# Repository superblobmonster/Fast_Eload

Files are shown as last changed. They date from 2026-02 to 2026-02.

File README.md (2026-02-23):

# Fast_Eload
Designed in KiCad 9.0.7 and FreeCAD 1.0.2

License: CC-BY-SA-4.0



## Design Specs
+ 10A/us slew rate
+ 15A RMS, 50A peak, 20A fuse
+ 100W (To be verified) average, peak power limited by FET SOA.
+ 100V input, 150V TVS protection, 250V+ rated parts.
+ 10V external power supply

## Design notes
+ Produce with 2oz copper
+ Fill and cap vias, or plate solid
+ Thinner PCB the better for thermal performance
+ Turn-off slew rates > 15A/us causes instability, root cause unknown

## Parts
+ CCA BOM: https://www.digikey.com/en/mylists/list/430F3M7L10

Additional parts/accessories:
+ Copper shim-stock: https://www.mcmaster.com/products/metals/copper-2~/shape~sheet/thickness~0-032/thickness~0-040/thickness~0-04/
+ TIM
+ Ring terminals
+ M3x4 screws
+ Amphenol MMCX to BNC: 095-850-207-006
+ Tektronix probe tip adaptor to BNC: 13036700
+ Ribbon cable assembly: 71600-308LF

## TODO and Notes
+ Validate thermal performance
+ Measure control bandwidth
+ Create control board with:
  + 10MS/s DAC
  + Slew rate limiting
  + V/I Monitoring: ADS7253?
    + Unregulation detection
    + SOA protections
  + Isolated input signal, 10MS/s ADC
  + Paralleling features, enable controls
+ Add temperature monitoring
+ Heatsink and interface design for equipment rack enclosure
+ Design a fully electrically isolated THT version with a SOT-227 FET

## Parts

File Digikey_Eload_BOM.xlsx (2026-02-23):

Country of Origin may be different at time of shipment.
The HTSUS and ECCN information shown is for informational purposes only and is not a representation or warranty as to the accuracy or reliability of these classifications. All information is provided "as is" and is subject to change without notice. Any use made of the information provided is without recourse to Digi-Key and at the user's risk.
Index | Manufacturer Part Number | Manufacturer Name | Qty Per Assembly | Description | Availability | Stock Status | Requested Part Number | Lead Weeks | Datasheet | Reference Designator | US Import Tariff | Note | Part Status | RoHS Status | REACH Status | Moisture Sensitivity Level (MSL) | ECCN | HTSUS | Country of Origin | Environmental Information | Original Part numbers | Unit of Measure | Image
1 | T491A106M016AT | KEMET | 1 | CAP TANT 10UF 20% 16V 1206 | 127,321 | In Stock | T491A106M016AT | 16 | https://yageogroup.com/content/datasheet/asset/file/KEM_T2005_T491 | C1 | N/A |  | Active | ROHS3 Compliant | REACH Unaffected | 1 (Unlimited) | EAR99 | 8532.21.0050 | Mexico |  | T491A106M016AT | EACH | https://mm.digikey.com/Volume0/opasdata/d220001/medias/images/2578/T491%20SERIES%203.2L%2C1.6W.jpg
2 | C0603C105K4RACTU | KEMET | 2 | CAP CER 1UF 16V X7R 0603 | 1,577,470 | In Stock | C0603C105K4RACTU | 12 | https://yageogroup.com/content/datasheet/asset/file/KEM_C1002_X7R_SMD | C2,C3 | N/A |  | Active | ROHS3 Compliant | REACH Unaffected | 1 (Unlimited) | EAR99 | 8532.24.0020 | Taiwan |  | C0603C105K4RACTU | EACH | https://mm.digikey.com/Volume0/opasdata/d220001/medias/images/4322/cut-tape-render.jpg
3 | C0603C202J5GACTU | KEMET | 1 | CAP CER 2000PF 50V C0G/NP0 0603 | 18,924 | In Stock | C0603C202J5GACTU | 13 | https://yageogroup.com/content/datasheet/asset/file/KEM_C1003_C0G_SMD | C4 | N/A |  | Active | ROHS3 Compliant | REACH Unaffected | 1 (Unlimited) | EAR99 | 8532.24.0020 | Mexico |  | C0603C202J5GACTU | EACH | https://mm.digikey.com/Volume0/opasdata/d220001/medias/images/5352/0603-%281608-Metric%29-Ceramic-Capacitor.jpg
4 | C0603C681F5GACTU | KEMET | 1 | CAP CER 680PF 50V C0G/NP0 0603 | 57,597 | In Stock | C0603C681F5GACTU | 11 | https://yageogroup.com/content/datasheet/asset/file/KEM_C1003_C0G_SMD | C6 | N/A |  | Active | ROHS3 Compliant | REACH Unaffected | 1 (Unlimited) | EAR99 | 8532.24.0020 | Mexico |  | C0603C681F5GACTU | EACH | https://mm.digikey.com/Volume0/opasdata/d220001/medias/images/5352/0603-%281608-Metric%29-Ceramic-Capacitor.jpg
5 | C0603C100J5GACTU | KEMET | 2 | CAP CER 10PF 50V C0G/NP0 0603 | 335,018 | In Stock | 399-C0603C100J5GACTUTR-ND | 13 | https://yageogroup.com/content/datasheet/asset/file/KEM_C1003_C0G_SMD | C7, C9 | N/A |  | Active | ROHS3 Compliant | REACH Unaffected | 1 (Unlimited) | EAR99 | 8532.24.0020 | Taiwan |  | 399-C0603C100J5GACTUTR-ND | EACH | https://mm.digikey.com/Volume0/opasdata/d220001/medias/images/4322/cut-tape-render.jpg
6 | C1206X103JAGACAUTO | KEMET | 1 | CAP CER 10000PF 250V NP0 1206 | 20,191 | In Stock | C1206X103JAGACAUTO | 20 | https://search.kemet.com/download/specsheet/C1206X103JAGACAUTO | C8 | N/A |  | Active | ROHS3 Compliant | REACH Unaffected | 1 (Unlimited) | EAR99 | 8532.24.0020 | Mexico |  | C1206X103JAGACAUTO | EACH | https://mm.digikey.com/Volume0/opasdata/d220001/medias/images/208/1206-%283216-Metric%29-3%2C20x1%2C60x1%2C00mm.jpg
7 | SM6T150A | STMicroelectronics | 1 | TVS DIODE 128VWM 207VC SMB | 7,339 | In Stock | SM6T150A | 13 | https://www.st.com/resource/en/datasheet/cd00000725.pdf | D1 | May apply on shipments to the U.S. |  | Active | ROHS3 Compliant | REACH Unaffected | 1 (Unlimited) | EAR99 | 8541.10.0080 | China |  | SM6T150A | EACH | https://mm.digikey.com/Volume0/opasdata/d220001/medias/images/6256/497%7ESMB%28DO214AA%29%7E%7E2.jpg
8 | DDZ5V6BSF-7 | Diodes Incorporated | 1 | DIODE ZENER 5.6V 500MW SOD323F | 9,376 | In Stock | DDZ5V6BSF-7DITR-ND | 24 | https://www.diodes.com/assets/Datasheets/ds31987.pdf | D2, D3 | May apply on shipments to the U.S. |  | Active | ROHS3 Compliant | REACH Unaffected | 1 (Unlimited) | EAR99 | 8541.10.0050 | China | https://mm.digikey.com/Volume0/opasdata/d220001/medias/docus/6731/Diode%20RoHS3%20REACH%20247%20Jan%202025%20Statement.pdf | DDZ5V6BSF-7DITR-ND | EACH | https://mm.digikey.com/Volume0/opasdata/d220001/medias/images/6210/31%7ESOD323F%7E%7E2.jpg
9 | 0683G9200-01 | Bel Fuse Inc. | 1 | FUSE CERM 20A 350VAC 125VDC 2SMD | 724 | In Stock | 0683G9200-01 | 8 | https://belfuse.com/media/datasheets/products/circuit-protection/ds-CP-0683G-series.pdf | F1 | May apply on shipments to the U.S. |  | Active | ROHS3 Compliant | REACH Unaffected | 1 (Unlimited) | EAR99 | 8536.10.0040 | China |  | 0683G9200-01 | EACH | https://mm.digikey.com/Volume0/opasdata/d220001/medias/images/4693/MFG_img-bcp-0683G_v1.jpg
10 | TSM-104-01-L-DV-P-TR | Samtec Inc. | 1 | CONN HEADER SMD 8POS 2.54MM | 9,183 | In Stock | SAM13286TR-ND | 4 | https://suddendocs.samtec.com/catalog_english/tsm.pdf | J1 | N/A |  | Active | ROHS3 Compliant | REACH Unaffected | 1 (Unlimited) | EAR99 | 8536.69.4040 | United States |  | SAM13286TR-ND | EACH | https://mm.digikey.com/Volume0/opasdata/d220001/medias/images/1118/TSM-8pos-01-gold-tin-DV.jpg
11 | 66012102111404 | Würth Elektronik | 4 | MMCX SMT PCB JACK, STRAIGHT, 5.0 | 16,256 | In Stock | 732-14187-2-ND | 16 | https://www.we-online.com/components/products/datasheet/66012102111404.pdf | J2, J4, J6, J7 | N/A | OPTIONAL | Active | ROHS3 Compliant | REACH Affected | Not Applicable | EAR99 | 8536.69.4010 | Taiwan | https://mm.digikey.com/Volume0/opasdata/d220001/medias/docus/744/Certificate_of_Compliance_ROHS.pdf | 732-14187-2-ND | EACH | https://mm.digikey.com/Volume0/opasdata/d220001/medias/images/695/MFG_66012102111404.jpg
12 | 7466203 | Würth Elektronik | 2 | TERM REDCUBE M3 1PIN SMD | 3,479 | In Stock | 7466203 | 18 | https://www.we-online.com/components/products/datasheet/7466203.pdf | J3,J5 | N/A |  | Active | ROHS3 Compliant | REACH Affected | 1 (Unlimited) | EAR99 | 8536.90.4000 | Germany | https://mm.digikey.com/Volume0/opasdata/d220001/medias/docus/744/Certificate_of_Compliance_ROHS.pdf | 7466203 | EACH | https://mm.digikey.com/Volume0/opasdata/d220001/medias/images/409/7466203.JPG
13 | 7449152022 | Würth Elektronik | 1 | FIXED IND 22NH 40A 0.55 MOHM SMD | 408 | In Stock | 7449152022 | 12 | https://www.we-online.com/components/products/datasheet/7449152022.pdf | L1 | May apply on shipments to the U.S. |  | Active | ROHS3 Compliant | REACH Unaffected | 1 (Unlimited) | EAR99 | 8504.50.8000 | China | https://mm.digikey.com/Volume0/opasdata/d220001/medias/docus/744/Certificate_of_Compliance_ROHS.pdf | 7449152022 | EACH | https://mm.digikey.com/Volume0/opasdata/d220001/medias/images/39/MFG_WE-ACHC-Series.jpg
14 | SGT070R70HTO | STMicroelectronics | 1 | 700 V, 53 MOHM TYP., 26 A, E-MOD | 426 | In Stock | 497-SGT070R70HTOTR-ND | 99 | https://www.st.com/resource/en/datasheet/sgt070r70hto.pdf | Q2 | N/A |  | Active | ROHS3 Compliant | REACH Unaffected | 3 (168 Hours) | EAR99 | 8541.29.0055 | China |  | 497-SGT070R70HTOTR-ND | EACH | https://mm.digikey.com/Volume0/opasdata/d220001/medias/images/6256/497%7EDM00276569%7E%7E8-View-2.jpg
15 | PWR263S-35-R100F | Bourns Inc. | 1 | RES 0.1 OHM 1% 35W D2PAK | 1,649 | In Stock | 118-PWR263S-35-R100F-ND | 8 | https://www.bourns.com/docs/Product-Datasheets/PWR263S-35.pdf | R1 | N/A |  | Active | ROHS3 Compliant | REACH Unaffected | 1 (Unlimited) | EAR99 | 8533.29.0000 | Costa Rica | https://www.bourns.com/docs/rohs-cofc/pwr2_coc.pdf?sfvrsn=edf9608a_6|https://www.bourns.com/docs/Product-MDS/PWR263S-35_MDS.pdf | 118-PWR263S-35-R100F-ND | EACH | https://mm.digikey.com/Volume0/opasdata/d220001/medias/images/6163/118%7ETO263-D2PAK%7E%7E2.jpg
16 | IGT65R025D2ATMA1 | Infineon Technologies | 0 | GANFET N-CH 650V 70A 8PSFN | 0 | Normally Stocking | IGT65R025D2ATMA1 | 18 | https://www.infineon.com/dgdl/Infineon-IGT65R025D2-DataSheet-v01_00-EN.pdf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 | Q2 | N/A | ALTERNATE | Active | ROHS3 Compliant | REACH Unaffected | 1 (Unlimited) | EAR99 | 8541.29.0055 | Germany |  | IGT65R025D2ATMA1 | EACH | https://mm.digikey.com/Volume0/opasdata/d220001/derivates/6/003/227/345/MFG_448%7EP-PG-HSOF-8-12%7E%7E8_web%28640x640%29.jpg
17 | D2TO035CR1000FTE3 | Vishay Sfernice | 0 | RES 0.1 OHM 1% 35W TO263 | 100 | In Stock | D2TO035CR1000FTE3 | 8 | https://www.vishay.com/docs/51058/d2to35.pdf | R1 | N/A | ALTERNATE | Active | ROHS3 Compliant | REACH Affected | 1 (Unlimited) | EAR99 | 8533.29.0000 | Czech Republic |  | D2TO035CR1000FTE3 | EACH | https://mm.digikey.com/Volume0/opasdata/d220001/derivates/6/003/240/902/MFG_716%7ETO263%28D2PAK%29%7E%7E2_web%28640x640%29.jpg
18 | CRCW060310K0FKEA | Vishay Dale | 6 | RES SMD 10K OHM 1% 1/8W 0603 | 4,084,407 | In Stock | CRCW060310K0FKEA | 12 | https://www.vishay.com/docs/20035/dcrcwe3.pdf | R2,R7,R10,R11,R19,R20 | N/A |  | Active | ROHS3 Compliant | REACH Unaffected | 1 (Unlimited) | EAR99 | 8533.21.0030 | Taiwan |  | CRCW060310K0FKEA | EACH | https://mm.digikey.com/Volume0/opasdata/d220001/medias/images/4322/cut-tape-render.jpg
19 | CRCW060349R9FKEA | Vishay Dale | 2 | RES SMD 49.9 OHM 1% 1/8W 0603 | 293,361 | In Stock | CRCW060349R9FKEA | 12 | https://www.vishay.com/docs/20035/dcrcwe3.pdf | R3,R4 | N/A |  | Active | ROHS3 Compliant | REACH Unaffected | 1 (Unlimited) | EAR99 | 8533.21.0030 | Taiwan |  | CRCW060349R9FKEA | EACH | https://mm.digikey.com/Volume0/opasdata/d220001/medias/images/4322/cut-tape-render.jpg
20 | CRCW060320R0FKEA | Vishay Dale | 2 | RES SMD 20 OHM 1% 1/8W 0603 | 122,766 | In Stock | CRCW060320R0FKEA | 12 | https://www.vishay.com/docs/20035/dcrcwe3.pdf | R5,R18 | N/A |  | Active | ROHS3 Compliant | REACH Unaffected | 1 (Unlimited) | EAR99 | 8533.21.0030 | Taiwan |  | CRCW060320R0FKEA | EACH | https://mm.digikey.com/Volume0/opasdata/d220001/medias/images/2491/CRCW%200603%20%281608metric%29.jpg
21 | CRCW06031M00FKEA | Vishay Dale | 2 | RES SMD 1M OHM 1% 1/8W 0603 | 264,389 | In Stock | 541-1.00MHCT-ND | 12 | https://www.vishay.com/docs/20035/dcrcwe3.pdf | R6, R21 | N/A |  | Active | ROHS3 Compliant | REACH Unaffected | 1 (Unlimited) | EAR99 | 8533.21.0030 | Israel |  | 541-1.00MHCT-ND | EACH | https://mm.digikey.com/Volume0/opasdata/d220001/medias/images/4322/cut-tape-render.jpg
22 | CRCW060310R0FKEA | Vishay Dale | 2 | RES SMD 10 OHM 1% 1/8W 0603 | 136,613 | In Stock | CRCW060310R0FKEA | 12 | https://www.vishay.com/docs/20035/dcrcwe3.pdf | R8,R16 | N/A |  | Active | ROHS3 Compliant | REACH Unaffected | 1 (Unlimited) | EAR99 | 8533.21.0030 | Taiwan |  | CRCW060310R0FKEA | EACH | https://mm.digikey.com/Volume0/opasdata/d220001/medias/images/4322/cut-tape-render.jpg
23 | CRCW06031K00FKEA | Vishay Dale | 4 | RES SMD 1K OHM 1% 1/8W 0603 | 754,225 | In Stock | CRCW06031K00FKEA | 12 | https://www.vishay.com/docs/20035/dcrcwe3.pdf | R12,R13,R14,R15 | N/A |  | Active | ROHS3 Compliant | REACH Unaffected | 1 (Unlimited) | EAR99 | 8533.21.0030 | Taiwan |  | CRCW06031K00FKEA | EACH | https://mm.digikey.com/Volume0/opasdata/d220001/medias/images/4322/cut-tape-render.jpg
24 | RCWE0805R100FKEA | Vishay Dale | 1 | RES 0.1 OHM 1% 1/4W 0805 | 88,338 | In Stock | RCWE0805R100FKEA | 15 | https://www.vishay.com/docs/20019/rcwe.pdf | R17 | N/A |  | Active | ROHS3 Compliant | REACH Unaffected | 1 (Unlimited) | EAR99 | 8533.21.0030 | Israel |  | RCWE0805R100FKEA | EACH | https://mm.digikey.com/Volume0/opasdata/d220001/medias/images/2584/TFPT%201206%20%283216metric%29.jpg
25 | 3214W-1-201E | Bourns Inc. | 2 | TRIMMER 200 OHM 0.25W J LEAD TOP | 17,775 | In Stock | 3214W-1-201E | 7 | https://www.bourns.com/docs/Product-Datasheets/3214.pdf | RV1,RV2 | N/A |  | Active | ROHS3 Compliant | REACH Affected | 1 (Unlimited) | EAR99 | 8533.40.8050 | Costa Rica | https://mm.digikey.com/Volume0/opasdata/d220001/medias/docus/6657/Bourns%20REACH%20247%20Jan%202025%20Statement.pdf|https://www.bourns.com/docs/rohs-cofc/cofc_trim4.pdf?sfvrsn=41f62244_2 | 3214W-1-201E | EACH | https://mm.digikey.com/Volume0/opasdata/d220001/medias/images/2375/3214W%20SERIES.jpg
26 | THJP0612AST1 | Vishay Dale Thin Film | 23 | THERMAL JUMPER 0612 30 MIL LEAD- | 29,155 | In Stock | THJP0612AST1 | 13 | https://www.vishay.com/docs/60157/thjp.pdf | TJ1,TJ2,TJ3,TJ4,TJ5,TJ6,TJ7,TJ8 | N/A |  | Active | ROHS3 Compliant | REACH Unaffected | 1 (Unlimited) | EAR99 | 8533.21.0030 | United States |  | THJP0612AST1 | EACH | https://mm.digikey.com/Volume0/opasdata/d220001/medias/images/210/MFG_THJP1225.jpg
27 | 5015 | Keystone Electronics | 5 | PC TEST POINT MINIATURE | 736,814 | In Stock | 36-5015TR-ND | 11 | https://www.keyelco.com/userAssets/file/M65p55.pdf | TP1,TP2,TP4,TP5,TP6,TP7,TP8,TP9,TP10 | May apply on shipments to the U.S. |  | Active | ROHS3 Compliant | REACH Unaffected | 1 (Unlimited) | EAR99 | 8536.90.4000 | China | https://www.keyelco.com/userAssets/file/RoHS_Statement.pdf|https://www.keyelco.com/userAssets/file/reach.pdf|https://www.keyelco.com/userAssets/file/Keystone-Prop65%20Declare2022.pdf | 36-5015TR-ND | EACH | https://mm.digikey.com/Volume0/opasdata/d220001/medias/images/827/5015.jpg
28 | ADA4807-4ARUZ-R7 | Analog Devices Inc. | 1 | IC OPAMP VFB 4 CIRCUIT 14TSSOP | 3,641 | In Stock | ADA4807-4ARUZ-R7 | 19 | https://www.analog.com/media/en/technical-documentation/data-sheets/ADA4807-1_4807-2_4807-4.pdf | U1 | N/A |  | Active | ROHS3 Compliant | REACH Unaffected | 1 (Unlimited) | EAR99 | 8542.33.0001 | Philippines |  | ADA4807-4ARUZ-R7 | EACH | https://mm.digikey.com/Volume0/opasdata/d220001/medias/images/4896/505%7ERU-14%7ERU%7E14.JPG

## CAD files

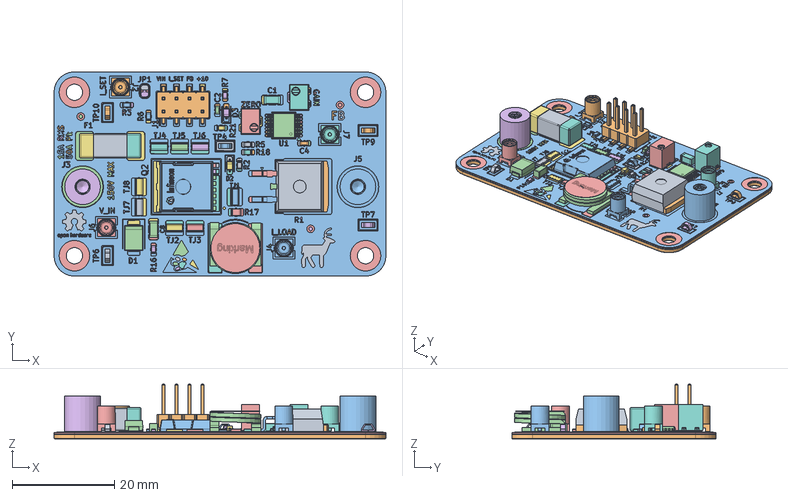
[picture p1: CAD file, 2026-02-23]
Heat_Spreader_Assy.FCStd
65.0 x 40.0 x 10.8 mm
FET_PLATE
GND_PLATE
R_0612_1632Metric
C_0603_1608Metric
MMCX_Wuerth_66012102111404
Wurth_Terminal_7466203_rev1
Ceramic_Fuse_0684L9400-01
Ceramic_Fuse_0684L9400-002
Ceramic_Fuse_0684L9400-003
R_0603_1608Metric
C_1206_3216Metric
Bourns_Pot_3214W
D_SOD-323
R_0612_1632Metric001
R_0603_1608Metric001
Modular_Load 1.13.1
Modular_Load 1.13.002
Modular_Load 1.13.003
Modular_Load 1.13.004
Modular_Load 1.13.005
R_0603_1608Metric002
R_0603_1608Metric003
R_0612_1632Metric002
R_0603_1608Metric004
MMCX_Wuerth_66012102111405
Wurth_Terminal_7466203_rev002
TSSOP-14_4.4x5mm_P0.65mm
R_0612_1632Metric003
R_0603_1608Metric005
PG-HSOF-8_3D
PG-HSOF-8_3D001
PG-HSOF-8_3D002
PG-HSOF-8_3D003
PG-HSOF-8_3D004
PG-HSOF-8_3D005
PG-HSOF-8_3D006
PG-HSOF-8_3D007
PG-HSOF-8_3D008
PG-HSOF-8_3D009
PG-HSOF-8_3D010
PG-HSOF-8_3D011
PG-HSOF-8_3D012
PG-HSOF-8_3D013
PG-HSOF-8_3D014
PG-HSOF-8_3D015
PG-HSOF-8_3D016
MMCX_Wuerth_66012102111406
PinHeader_2x04_P2.54mm_Vertical_SMD
MMCX_Wuerth_66012102111407
Core
Foil
R_0612_1632Metric004
D_SOD-324
C_1206_3216Metric001
R_0603_1608Metric006
D_SMB
R_0805_2012Metric
R_0612_1632Metric005
Bourns_Pot_3214W001
R_0612_1632Metric006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

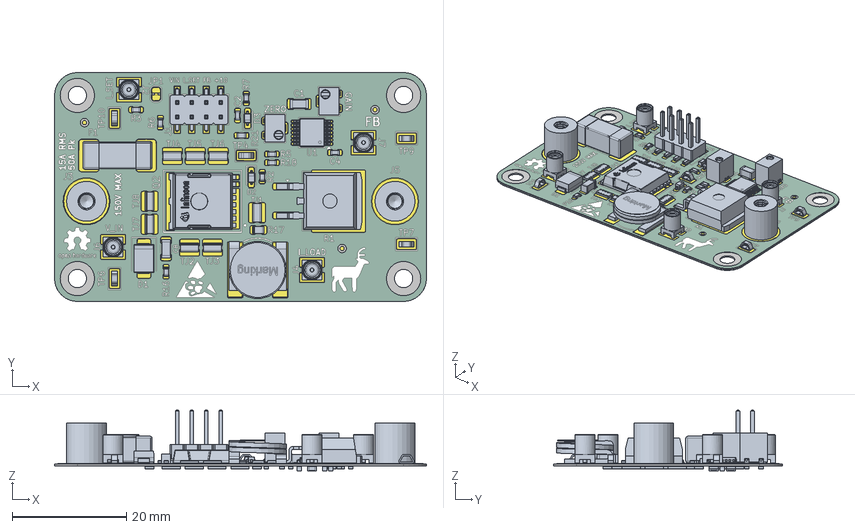
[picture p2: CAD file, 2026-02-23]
3D_Models/Modular_Load.step
65.0 x 40.0 x 10.6 mm
R_0612_1632Metric x 23
C_0603_1608Metric x 6
MMCX_Wuerth_66012102111404 x 4
Wurth_Terminal_7466203_rev1 x 2
Ceramic_Fuse_0684L9400-01
R_0603_1608Metric x 18
C_1206_3216Metric x 2
Bourns_Pot_3214W x 2
D_SOD-323 x 2
Modular_Load 1.13.1
TSSOP-14_4.4x5mm_P0.65mm
PG-HSOF-8_3D
PinHeader_2x04_P2.54mm_Vertical_SMD
Core
Foil
D_SMB
R_0805_2012Metric
Modular_Load_copper
Modular_Load_silkscreen x 2
Modular_Load_soldermask x 2
Modular_Load_PCB

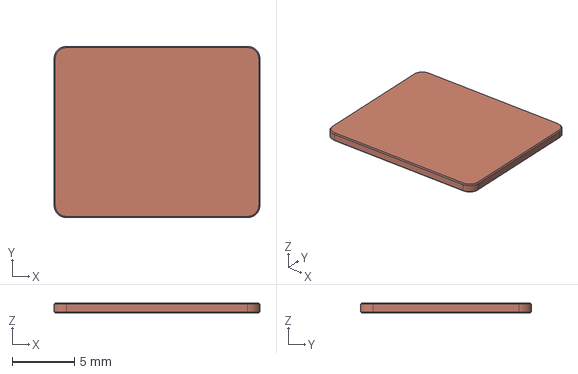
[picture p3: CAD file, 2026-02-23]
3D_Models/FET_PLATE.step
16.6 x 13.8 x 0.81 mm

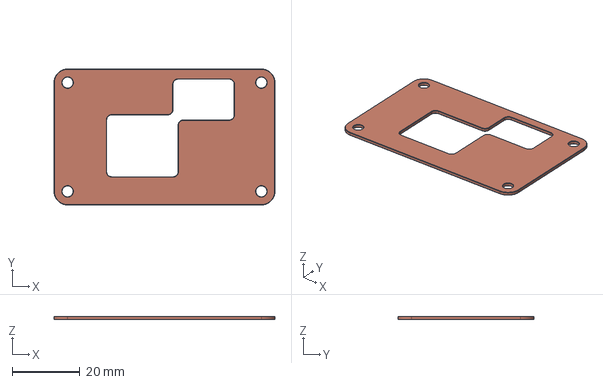
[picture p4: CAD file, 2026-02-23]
3D_Models/GND_PLATE.step
65.0 x 40.0 x 1.00 mm

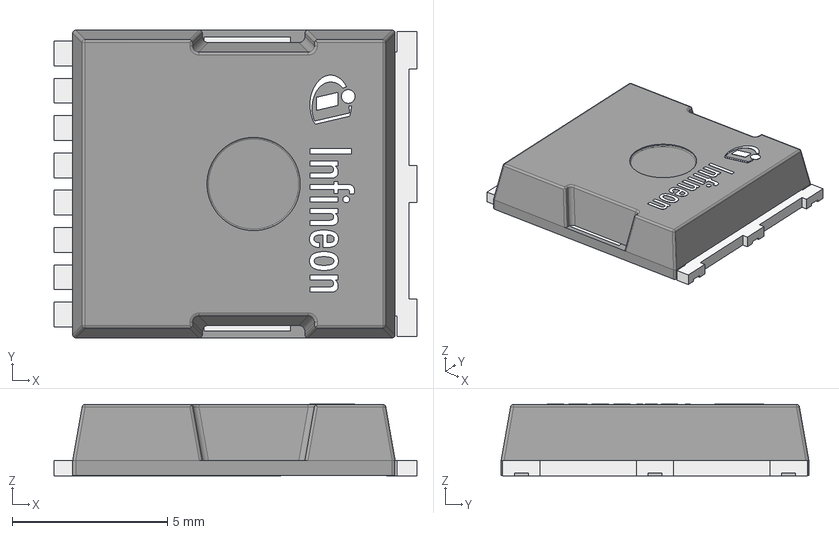
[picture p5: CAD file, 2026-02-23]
3D_Models/PG-HSOF-8_3D.stp
11.7 x 9.90 x 2.31 mm

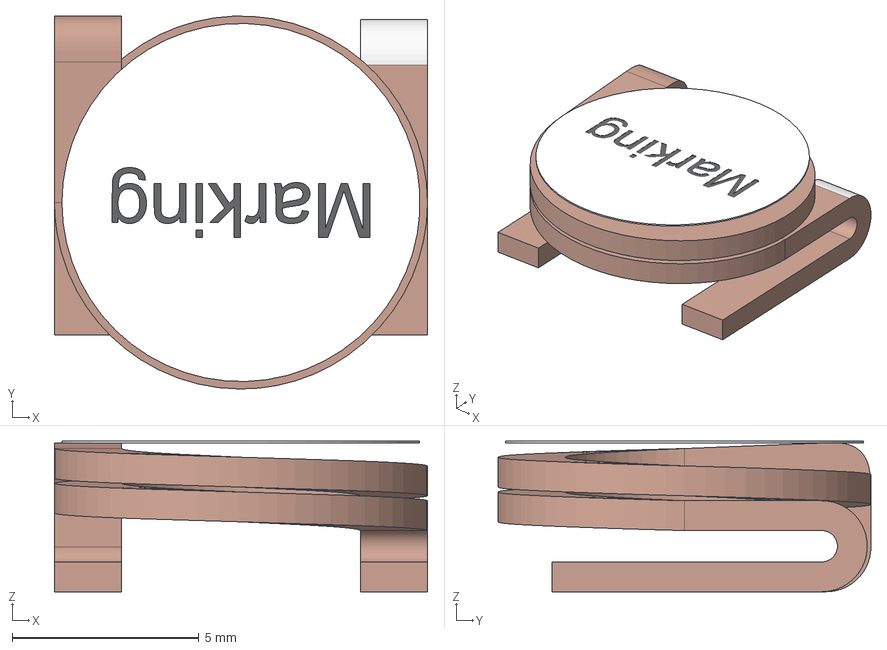
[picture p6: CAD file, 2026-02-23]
3D_Models/Inductor_WE-ACHC-7449150023Rev1.stp
10.0 x 10.00 x 4.04 mm
Core
Foil

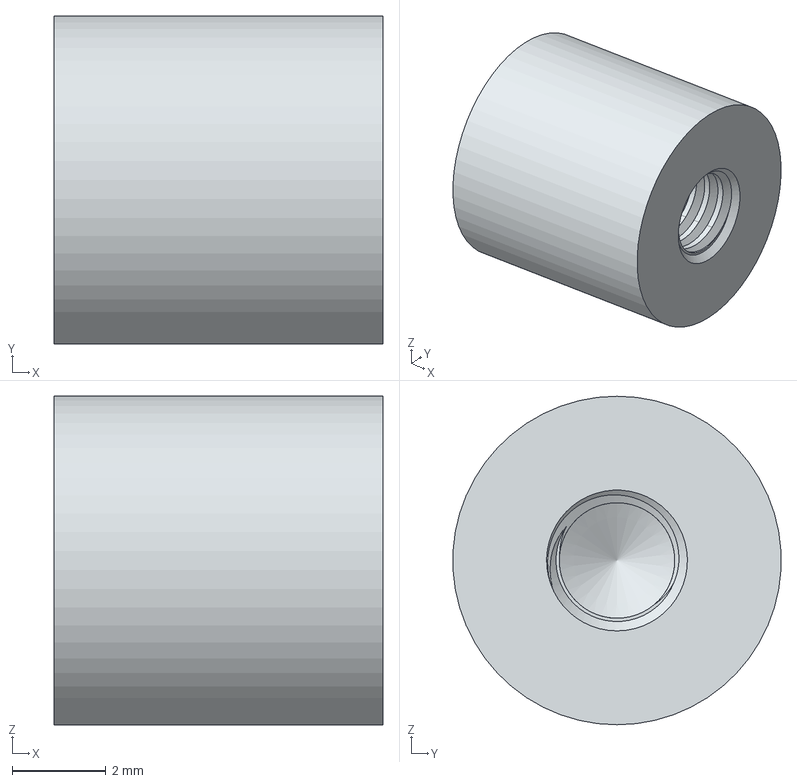
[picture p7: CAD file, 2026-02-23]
3D_Models/Wurth_Terminal_7466203_rev1.stp
7.00 x 6.99 x 7.00 mm

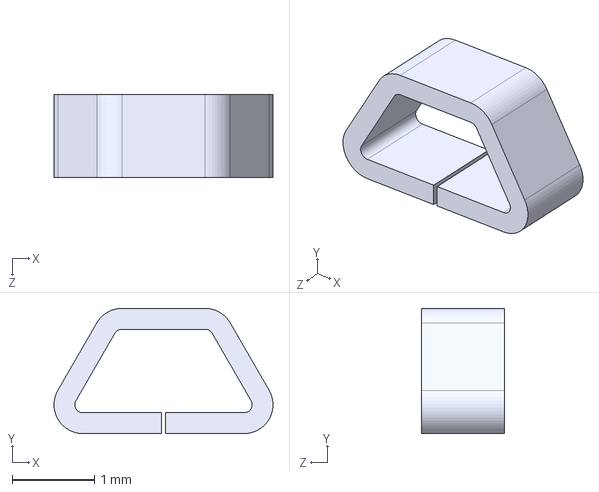
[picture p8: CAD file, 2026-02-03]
3D_Models/5015.step
2.67 x 1.52 x 1.02 mm

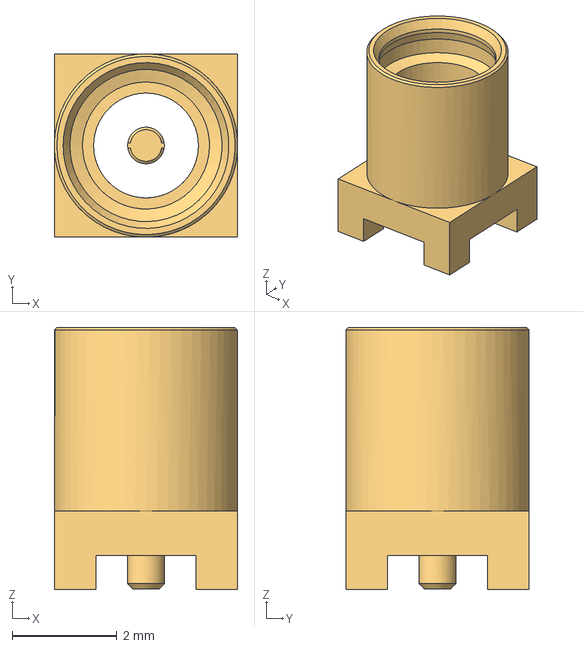
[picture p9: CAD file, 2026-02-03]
3D_Models/MMCX_Wuerth_66012102111404.stp
3.50 x 3.50 x 5.00 mm

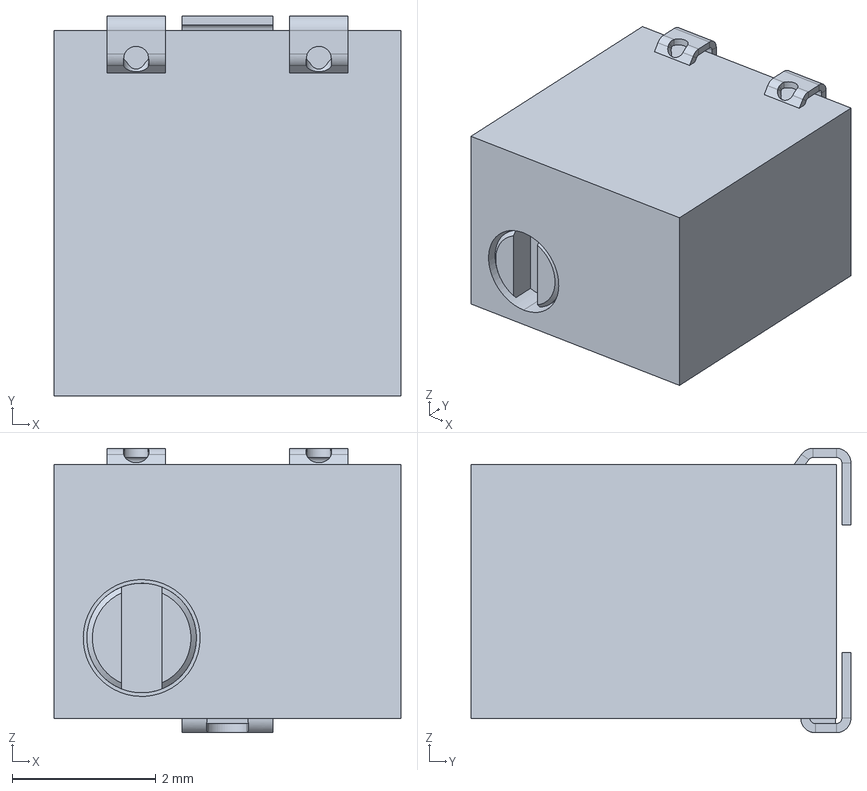
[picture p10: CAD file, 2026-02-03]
3D_Models/Bourns_Pot_3214W.stp
4.83 x 5.28 x 3.96 mm

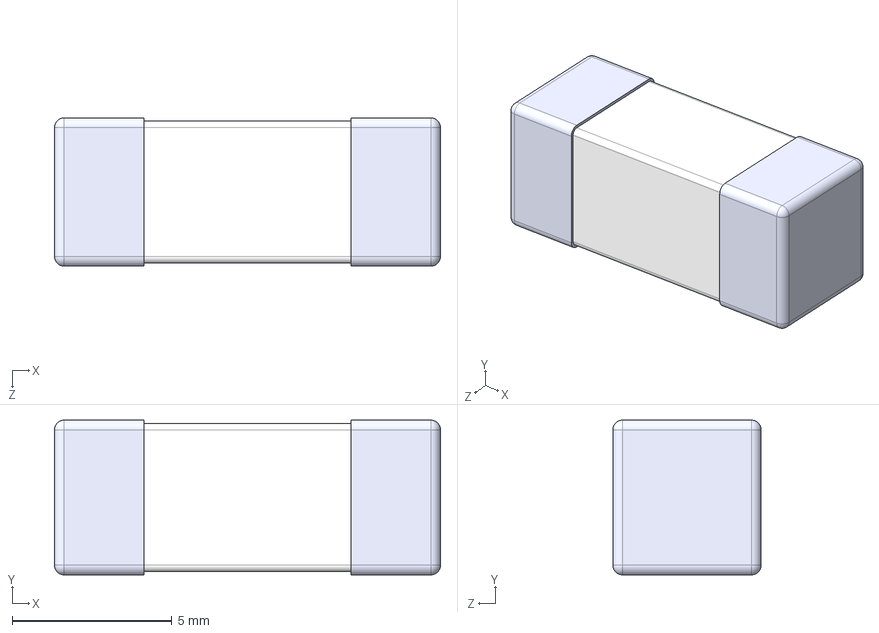
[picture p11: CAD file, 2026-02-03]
3D_Models/Ceramic_Fuse_0684L9400-01.step
12.1 x 4.85 x 4.65 mm

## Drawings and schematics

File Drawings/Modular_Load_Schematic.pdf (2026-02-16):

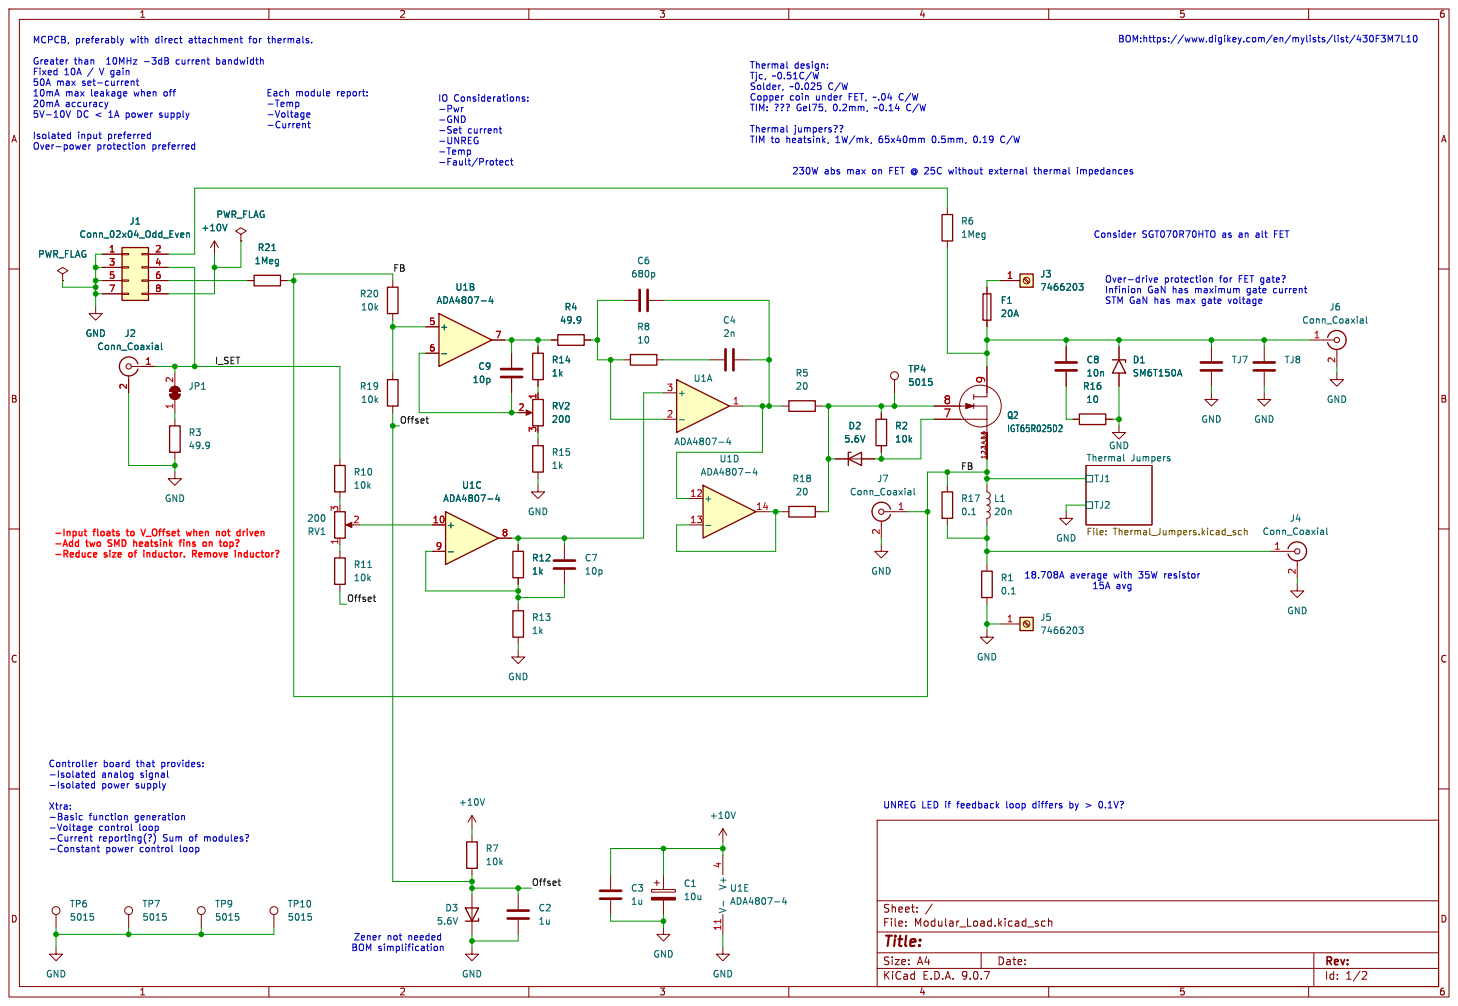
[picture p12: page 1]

Each module report: -Temp

TJ1 TJ2 Thermal Jumpers File: Thermal_Jumpers.kicad_sch GNDV+

-Add two SMD heatsink fins on top?

18.708A average with 35W resistor 15A avg

Id: 1/2 Title: File: Modular_Load.kicad_sch Sheet: /

Zener not needed BOM simplification

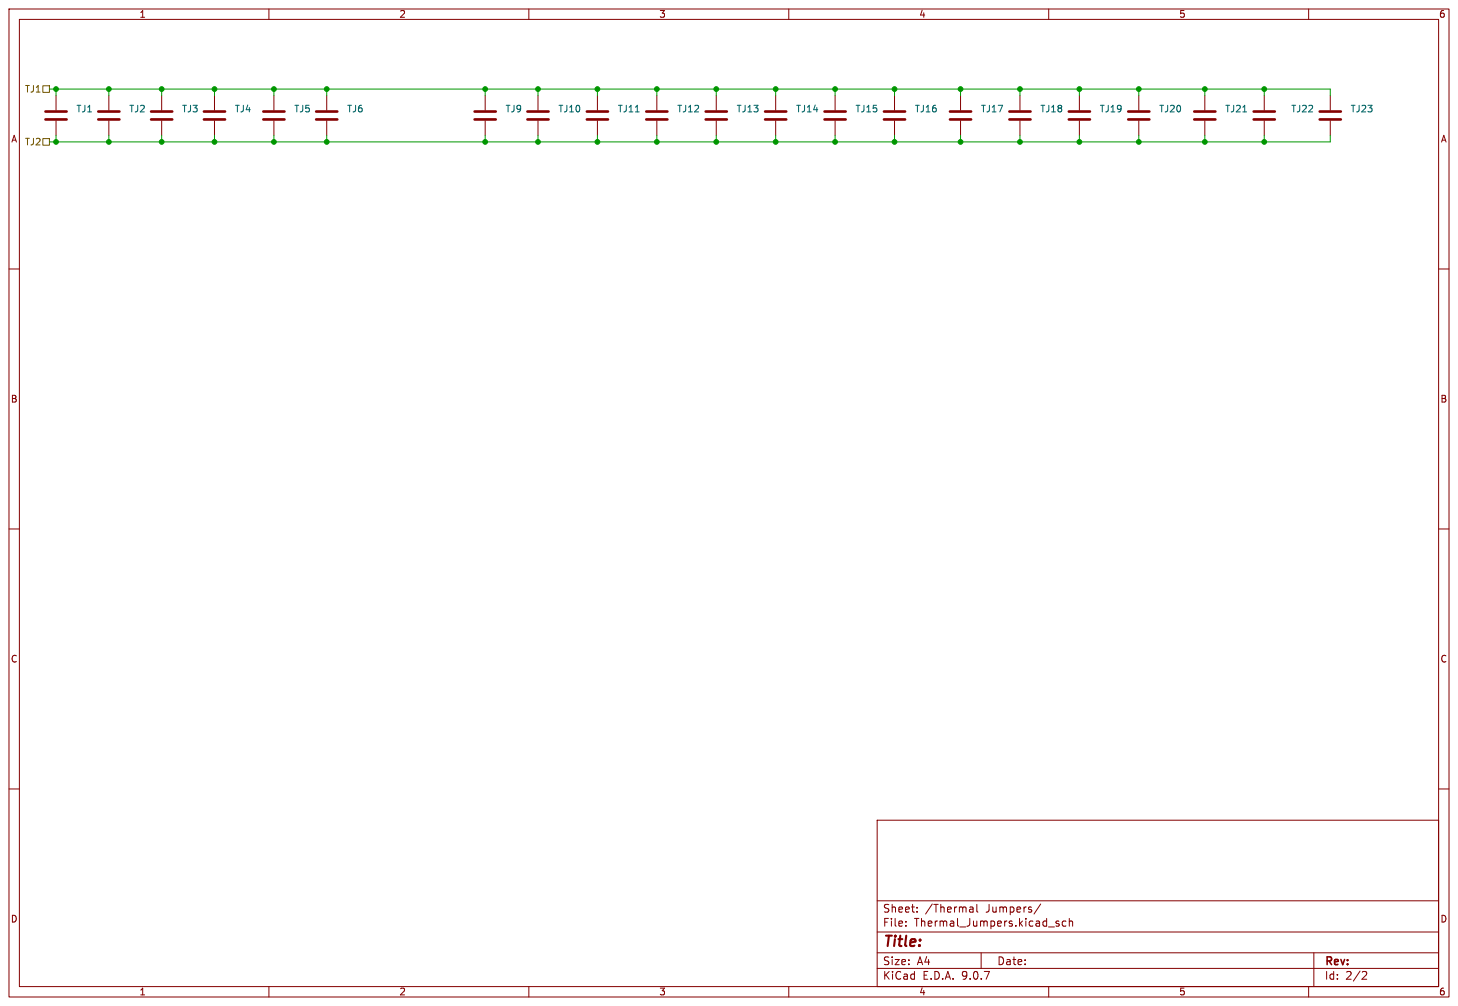
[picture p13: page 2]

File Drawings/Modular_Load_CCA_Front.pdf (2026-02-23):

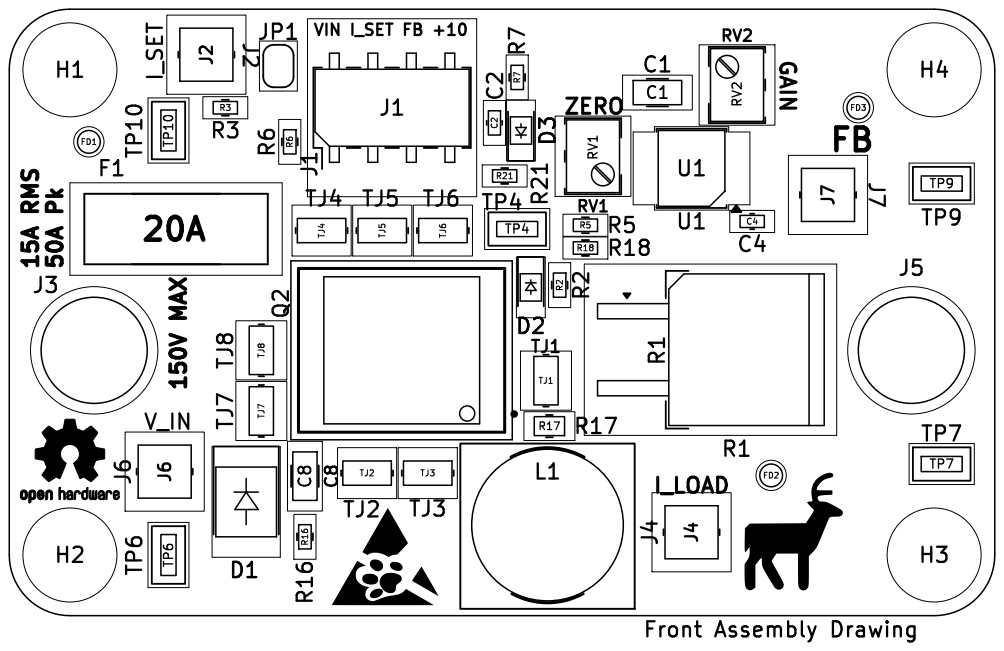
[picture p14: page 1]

Id: 1/1 Title: File: Modular_Load.kicad_pcb Sheet:

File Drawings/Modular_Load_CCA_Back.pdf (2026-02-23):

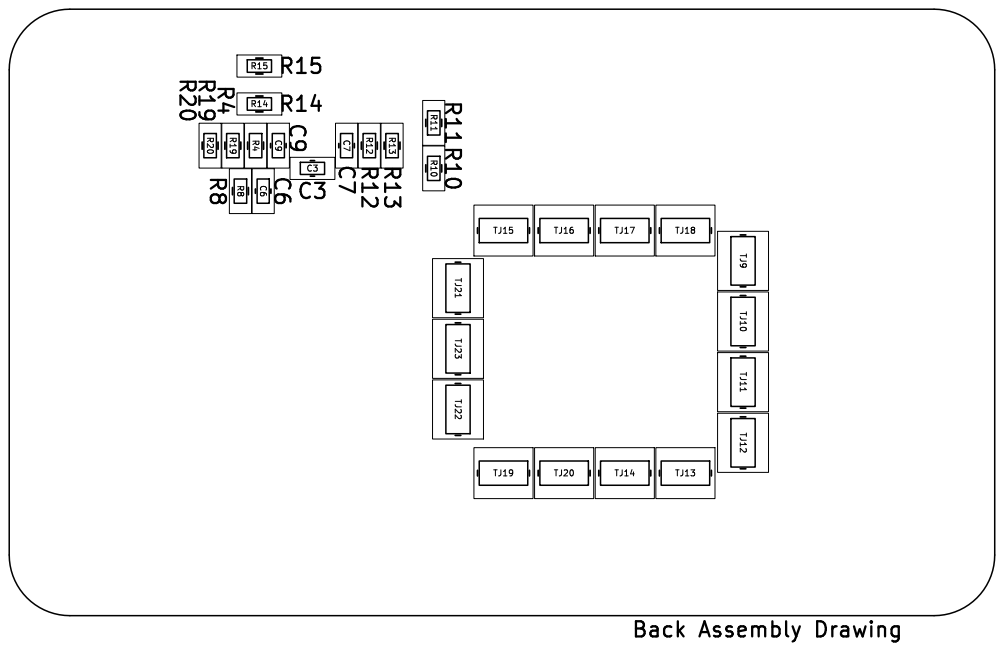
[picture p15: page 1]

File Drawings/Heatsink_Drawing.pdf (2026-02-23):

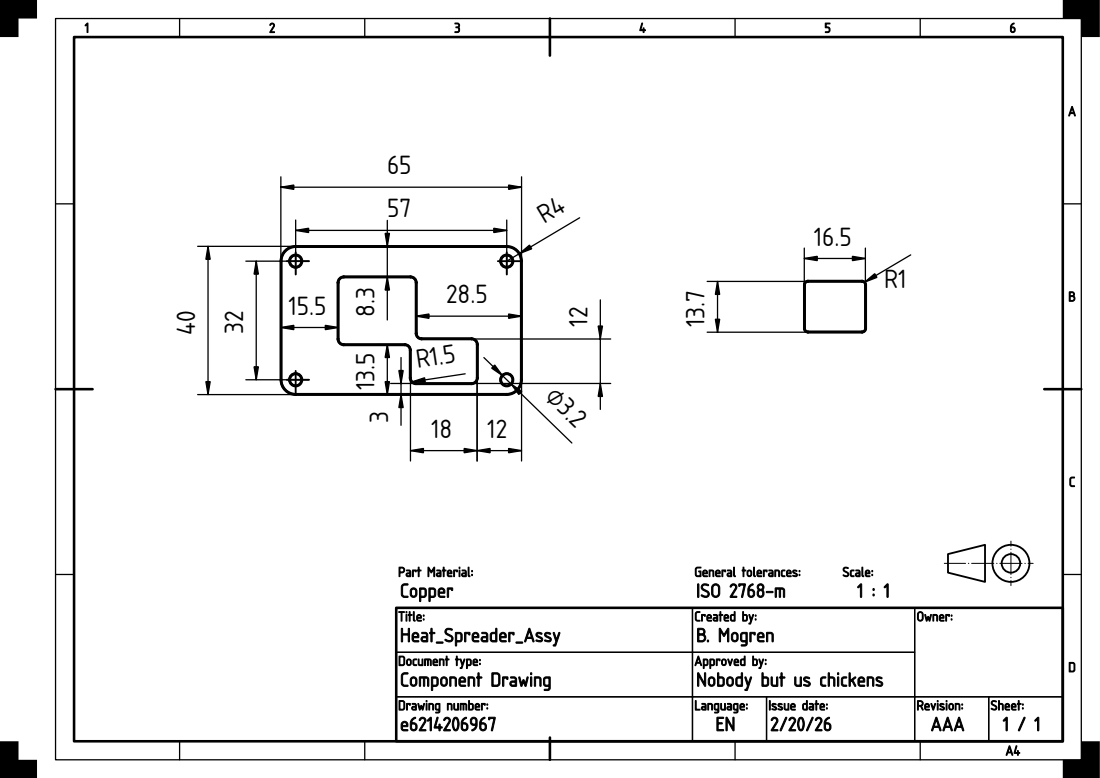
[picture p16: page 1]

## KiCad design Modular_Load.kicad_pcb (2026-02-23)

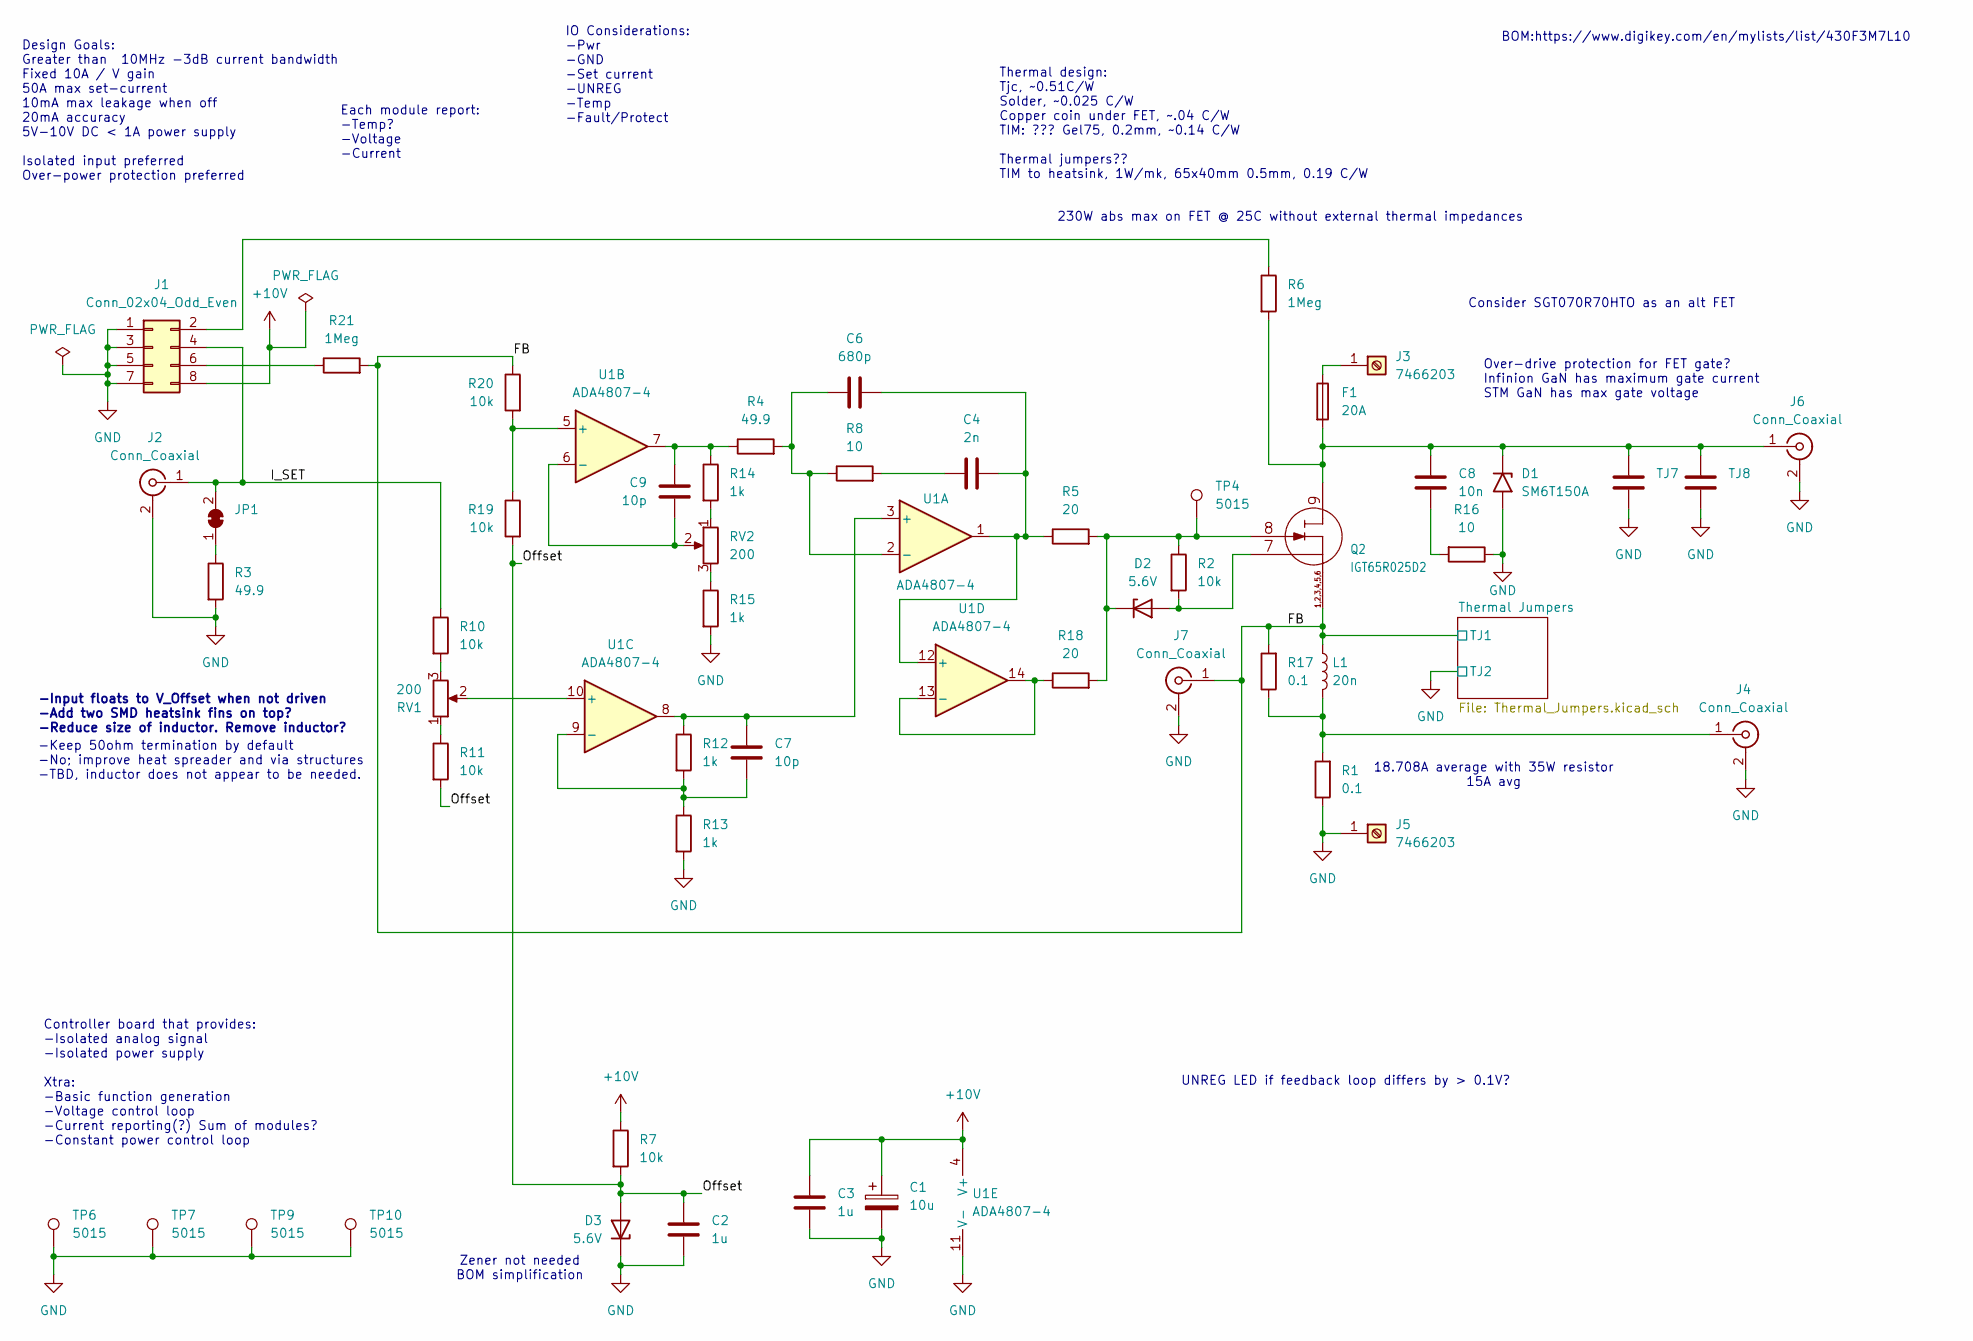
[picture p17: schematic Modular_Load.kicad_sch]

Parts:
C1: 10u; C_1206_3216Metric; PartNumber T491A106M016AT
C2, C3: 1u; C_0603_1608Metric; PartNumber C0603C105K4RACTU
C4: 2n; C_0603_1608Metric; PartNumber C0603C202J5GACTU
C6: 680p; C_0603_1608Metric; PartNumber C0603C681F5GACTU
C7, C9: 10p; C_0603_1608Metric; PartNumber C0603C100J5GACTU
C8: 10n; C_1206_3216Metric; PartNumber C1206X103JAGACAUTO
D1: SM6T150A; D_SMB; PartNumber SM6T150A
D2, D3: 5.6V; D_SOD-323_HandSoldering; PartNumber DDZ5V6BSF-7
F1: 20A; FUSE_0683G9200-01; PartNumber 0683G9200-01
J1: Conn_02x04_Odd_Even; PinHeader_2x04_P2.54mm_Vertical_SMD; PartNumber TSM-104-01-L-DV-P-TR
J2, J4, J6, J7: Conn_Coaxial; WR-MMCX_Wuerth_66012102111404_Vertical; PartNumber 66012102111404
J3, J5: 7466203; WP-SMBU_7466203; PartNumber 7466203
JP1: SolderJumper_2_Bridged; SolderJumper-2_P1.3mm_Bridged_RoundedPad1.0x1.5mm
L1: 20n; WE-ACHC_7449150023; PartNumber 7449152022
Q2: IGT65R025D2; IFX-PG-HSOF-8-12-V; PartNumber IGT65R025D2ATMA1
R1: 0.1; TO-263-2_TabPin1; PartNumber D2TO035CR1000FTE3
R2, R7, R10, R11, R19, R20: 10k; R_0603_1608Metric; PartNumber CRCW060310K0FKEA
R3, R4: 49.9; R_0603_1608Metric; PartNumber CRCW060349R9FKEA
R5, R18: 20; R_0603_1608Metric; PartNumber CRCW060320R0FKEA
R6, R21: 1Meg; R_0603_1608Metric; PartNumber CRCW06031M00FKEA
R8, R16: 10; R_0603_1608Metric; PartNumber CRCW060310R0FKEA
R12, R13, R14, R15: 1k; R_0603_1608Metric; PartNumber CRCW06031K00FKEA
R17: 0.1; R_0805_2012Metric; PartNumber RCWE0805R100FKEA
RV1, RV2: 200; Potentiometer_Bourns_3214W_Vertical; PartNumber 3214W-1-201E
TJ7, TJ8: THJP0612ABT1; R_0612_1632Metric_Pad1.18x3.40mm_HandSolder; PartNumber THJP0612AST1
TP4, TP6, TP7, TP9, TP10: 5015; TestPoint_Keystone_5015_Micro_Mini; PartNumber 5015
U1: ADA4807-4; TSSOP-14_4.4x5mm_P0.65mm; PartNumber ADA4807-4ARUZ-R7

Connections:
+10V: C1.1, C3.1, J1.8, R7.1, U1.4 (V+)
/FB: J7.1 (In), L1.1, Q2.1 (S1), Q2.2 (S2), Q2.3 (S3), Q2.4 (S4), Q2.5 (S5), Q2.6 (S6), R17.2, R20.1, R21.2; also elsewhere on the board
/I_SET: J1.4, J2.1 (In), JP1.2 (B), R10.1
/Offset: C2.1, D3.2 (A), R7.2, R11.2, R19.2
GND: C1.2, C2.2, C3.2, D1.2 (A2), D3.1 (K), J1.1, J1.3, J1.5, J1.7, J2.2 (Ext), J4.2 (Ext), J5.1, J6.2 (Ext), J7.2 (Ext), R1.1, R3.2, R13.2, R15.2, R16.1, TJ7.2, TJ8.2, TP6.1, TP7.1, TP9.1, TP10.1, U1.11 (V-); also elsewhere on the board
unnamed: C4.1, R8.2
unnamed: C8.2, R16.2
unnamed: C9.1, R4.1, R14.1, U1.7
unnamed: C8.1, D1.1 (A1), F1.2, J6.1 (In), Q2.9 (D), R6.2, TJ7.1, TJ8.1
unnamed: D2.2 (A), Q2.7 (SK), R2.2
unnamed: D2.1 (K), Q2.8 (G), R2.1, R5.2, R18.2, TP4.1
unnamed: J1.2, R6.1
unnamed: J1.6, R21.1
unnamed: F1.1, J3.1
unnamed: J4.1 (In), L1.2, R1.2, R17.1
unnamed: JP1.1 (A), R3.1
unnamed: R10.2, RV1.3
unnamed: R11.1, RV1.1
unnamed: R14.2, RV2.1
unnamed: R15.1, RV2.3
unnamed: C7.1, R12.1, U1.3 (+), U1.8
unnamed: C6.1, R4.2, R8.1, U1.2 (-)
unnamed: R19.1, R20.2, U1.5 (+)
unnamed: C9.2, RV2.2, U1.6 (-)
unnamed: RV1.2, U1.10 (+)
unnamed: C7.2, R12.2, R13.1, U1.9 (-)
unnamed: C4.2, C6.2, R5.1, U1.1, U1.12 (+)
unnamed: R18.1, U1.13 (-), U1.14

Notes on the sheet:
BOM:https://www.digikey.com/en/mylists/list/430F3M7L10
Thermal design: Tjc, ~0.51C/W Solder, ~0.025 C/W Copper coin under FET, ~.04 C/W TIM: ??? Gel75, 0.2mm, ~0.14 C/W Thermal jumpers?? TIM to heatsink, 1W/mk, 65x40mm 0.5mm, 0.19 C/W
230W abs max on FET @ 25C without external thermal impedances
Zener not needed BOM simplification
UNREG LED if feedback loop differs by > 0.1V?
Over-drive protection for FET gate? Infinion GaN has maximum gate current STM GaN has max gate voltage
18.708A average with 35W resistor 15A avg
Consider SGT070R70HTO as an alt FET
IO Considerations: -Pwr -GND -Set current -UNREG -Temp -Fault/Protect
-Input floats to V_Offset when not driven -Add two SMD heatsink fins on top? -Reduce size of inductor. Remove inductor?
Design Goals: Greater than 10MHz -3dB current bandwidth Fixed 10A / V gain 50A max set-current 10mA max leakage when off 20mA accuracy 5V-10V DC < 1A power supply Isolated input preferred Over-power protection preferred
Controller board that provides: -Isolated analog signal -Isolated power supply Xtra: -Basic function generation -Voltage control loop -Current reporting(?) Sum of modules? -Constant power control loop
-Keep 50ohm termination by default -No; improve heat spreader and via structures -TBD, inductor does not appear to be needed.
Each module report: -Temp? -Voltage -Current

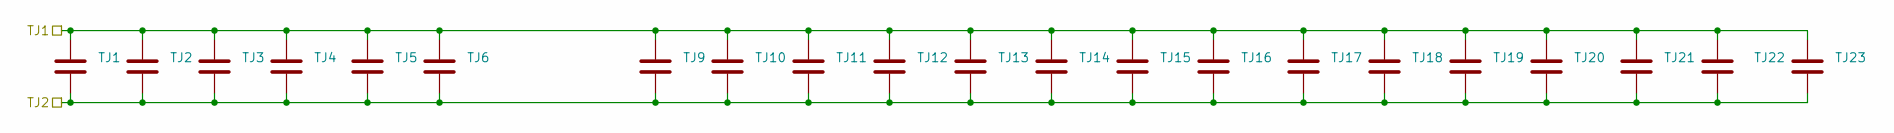
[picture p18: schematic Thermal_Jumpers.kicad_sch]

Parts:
TJ1, TJ2, TJ3, TJ4, TJ5, TJ6, TJ9, TJ10, TJ11, TJ12, TJ13, TJ14, TJ15, TJ16, TJ17, TJ18, TJ19, TJ20, TJ21, TJ22, TJ23: THJP0612ABT1; R_0612_1632Metric_Pad1.18x3.40mm_HandSolder; PartNumber THJP0612AST1

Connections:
/FB: TJ1.1, TJ2.1, TJ3.1, TJ4.1, TJ5.1, TJ6.1, TJ9.1, TJ10.1, TJ11.1, TJ12.1, TJ13.1, TJ14.1, TJ15.1, TJ16.1, TJ17.1, TJ18.1, TJ19.1, TJ20.1, TJ21.1, TJ22.1, TJ23.1; also elsewhere on the board
GND: TJ1.2, TJ2.2, TJ3.2, TJ4.2, TJ5.2, TJ6.2, TJ9.2, TJ10.2, TJ11.2, TJ12.2, TJ13.2, TJ14.2, TJ15.2, TJ16.2, TJ17.2, TJ18.2, TJ19.2, TJ20.2, TJ21.2, TJ22.2, TJ23.2; also elsewhere on the board

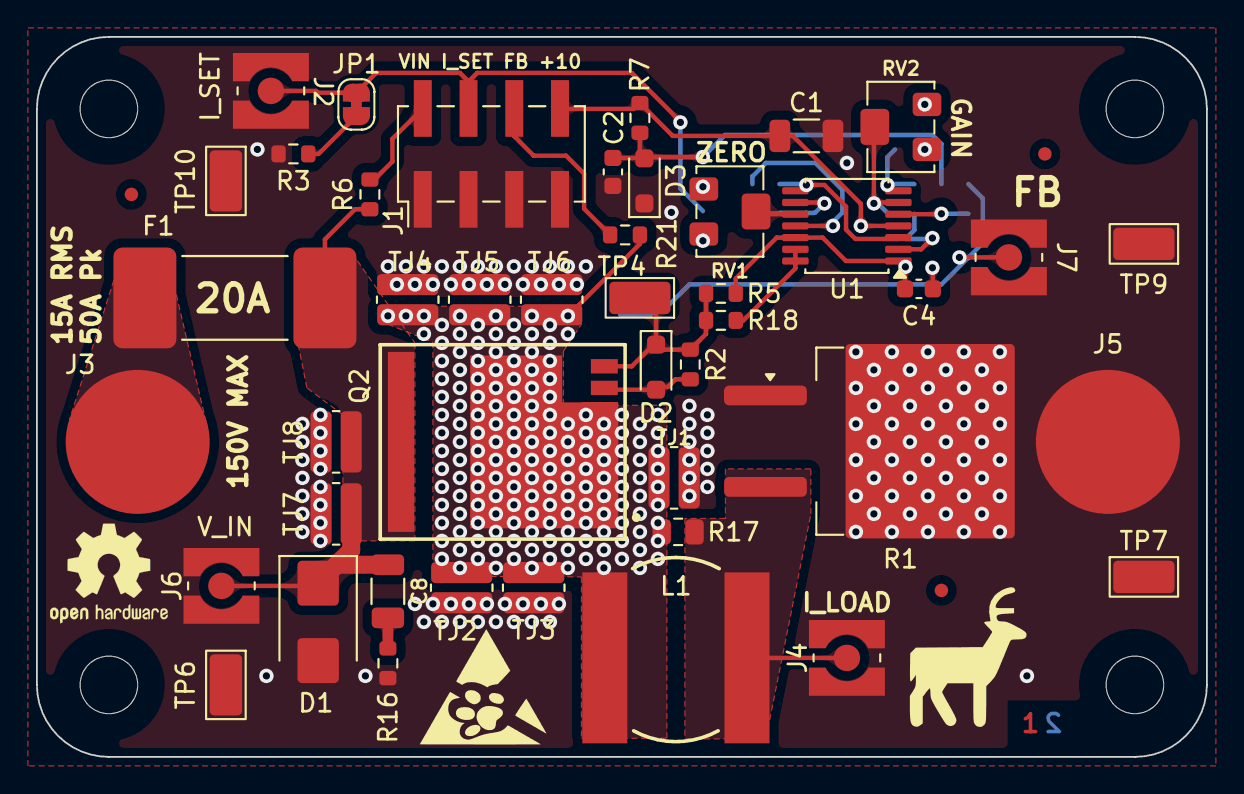
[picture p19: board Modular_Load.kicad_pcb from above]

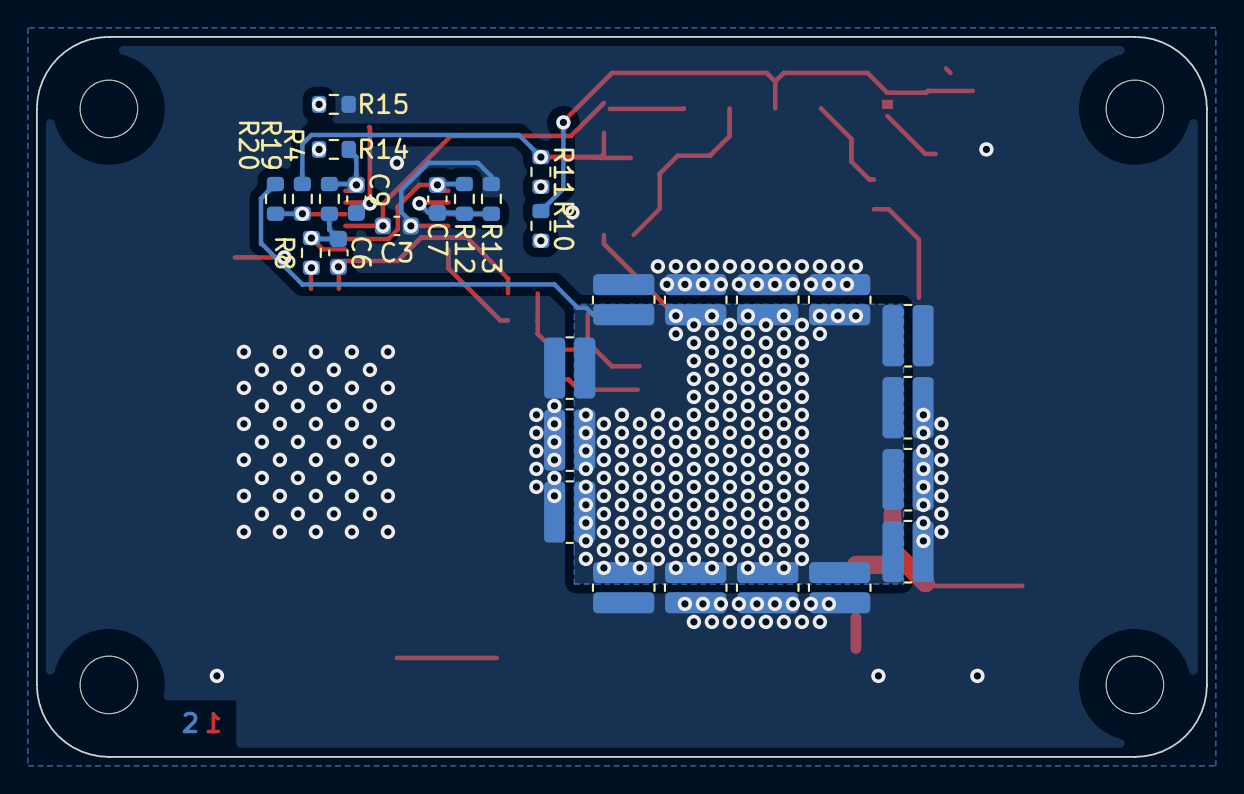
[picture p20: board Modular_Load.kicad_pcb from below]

Board: 2 copper layers, 65.0 x 40.0 mm, 84 parts (29 on the bottom side), 28 nets.

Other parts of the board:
FD1, FD2, FD3: Fiducial_0.75mm_Mask1.5mm
G1, G2: LOGO
G3: OSHW-Logo2_7.3x6mm_SilkScreen
H1, H2, H3, H4: MountingHole_3.2mm_M3_ISO7380
Layers: LayerMarker_2_3.81x2.54mm_TextH1mm_P1.27mm_Bottom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; LayerMarker_2_3.81x2.54mm_TextH1mm_P1.27mm_BottomMirrored

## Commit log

2025-12-27 Initial commit
    Fab files for v1
    [Modular_Load.kicad_pcb, Modular_Load.kicad_sch]
2026-02-03 Add files via upload
    V2, added MMCX connectors, adjusted gain tuning, changed control connector, thermal layout update.
    [5015.step, Bourns_Pot_3214W.stp, Ceramic_Fuse_0684L9400-01.step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]
2026-02-16 V3 Update
    Thermal improvements, double-sided assembly, better reference stability
    [Heat_Spreader_Assy.FCStd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]
2026-02-16 Update README.md
    ADC notes
2026-02-16 Documentation update
    Additional documentation, updated BOM, schematic, and CCA drawings
    [ELOAD_BOM.csv, Modular_Load.kicad_sch]
2026-02-23 Folder clean-up
    [5015.step, Bourns_Pot_3214W.stp, Ceramic_Fuse_0684L9400-01.step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]
2026-02-23 Added heatsink drawings, updated component 3D models
    [ELOAD_BOM.csv, Heat_Spreader_Assy.FCStd, Inductor_WE-ACHC-7449150023Rev1.stp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]
2026-02-23 Update README.md
    Updated board image
2026-02-23 FET 3D model, Fresh FAB export, updated README
    [Modular_Load-B_Cu.gbr, Modular_Load-B_Mask.gbr, Modular_Load-B_Paste.gbr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]
2026-02-23 Updated Heatsink Models
    [FET_PLATE.step, GND_PLATE.step, Heat_Spreader_Assy.FCStd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]
2026-02-23 Added digikey BOM export
    [Digikey_Eload_BOM.xlsx]
2026-02-23 Digikey BOM quantities update
    [Digikey_Eload_BOM.xlsx]
2026-02-23 Assembly Doccumentation Updates
    [Modular_Load-B_Cu.gbr, Modular_Load-B_Mask.gbr, Modular_Load-B_Paste.gbr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]
